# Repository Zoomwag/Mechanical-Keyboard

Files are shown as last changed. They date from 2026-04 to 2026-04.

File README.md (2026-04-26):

# Mechanical Keyboard

Render 1
Render 2
Render 3

These are some high-quality renders of the keyboard design.

---

## Overview

This is a custom mechanical keyboard that I designed from scratch. It is a **60% layout** and runs on a **Raspberry Pi Pico** using **QMK firmware**.

The goal of this project was to make the keyboard:
- Easy to build  
- Affordable and accessible  
- Fully DIY-friendly  

All components are **through-hole (THT)**, making soldering much easier—especially for beginners. The entire keyboard is assembled using just **four M3 screws**, keeping the construction simple and clean.

The case is fully **3D printable**, and the keycaps can either be 3D printed or purchased. I recommend buying keycaps for better durability and finish.

The keyboard uses **Cherry MX-style switches**, so you can choose whichever type suits your preference. I will likely be using **Cherry MX Red switches** for a smooth, linear feel.

---

## PCB

### PCB Layout
PCB Layout

### Schematic
Schematic

### 3D PCB Model
PCB 3D

### Fully Assembled PCB (3D View)
Assembled PCB 1
Assembled PCB 2
Assembled PCB 3

---

## Case

### Top Shell
Top Case

### Bottom Shell
Bottom Case

### Full Case (No Electronics)
Empty Case

### Electronics Installed
Assembled Case

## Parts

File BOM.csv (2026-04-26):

Name | Purpose | Quantity | Total Cost (USD) | Link | Distributor
UGREEN 3A USB Type C Cable For iPhone 17 16 Xiaomi Samsung Fast Charging Wire USB-C Charger Data Cord For iPad Poco USB C | cable | 1 | 3.00 | https://www.aliexpress.com/item/1005006471612403.html?mp=1 | ALiexpress
Pi pico | MCU | 1 | 3.00 | https://www.aliexpress.com/item/1005005617180169.html?curPageLogUid=uMiuSRCoFOSS | Aliexpress
Customization PCB Satellite Axis For Cherry Mechanical Keyboard OEM Plate mounted Black 6.25u 2u Stabilizers Modifier Keys | Stabalizers | 1 | 6.00 | https://www.aliexpress.com/item/1005001686299616.html?mp=1 | Aliexpress
125 Keys Minimalist White Japanese Keycaps For MX Switch Mechanical Keyboard Cherry Profile Dye Sublimation PBT Key Caps Custom | Keycaps | 1 | 12.00 | https://www.aliexpress.com/item/1005009695266144.html?curPageLogUid=n6jaXa30P5yE | AliExpress
100PCS do-35 1N4148 IN4148 High-speed switching diodes New In Stock | diodes | 2 | 2.00 | https://www.aliexpress.com/item/1005008962041349.html?curPageLogUid=TPSj3bbLctze | Aliexpress
10~120Pc Original Cherry MX Mechanical Keyboard Switches Red Blue Brown Black Silver Pink Linear Tactile Cherry Clear RGB Switch | switches | 1 | 24.00 | https://www.aliexpress.com/item/1005007907313874.html?curPageLogUid=7ZZJ3L4R22EP | ALiexpress
Pcb | Pcb | 1 | 20.30 | https://jlcpcb.com/ | jlcpcb

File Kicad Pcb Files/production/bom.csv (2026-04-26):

Designator | Footprint | Quantity | Value | LCSC Part #
A1 | RaspberryPi_Pico_Common_Unspecified | 1 | RaspberryPi_Pico
D1, D10, D11, D12, D13, D14, D15, D16, D17, D18, D19, D2, D20, D21, D22, D23, D24, D25, D26, D27, D28, D29, D3, D30, D31, D32, D33, D34, D35, D36, D37, D38, D39, D4, D40, D41, D42, D43, D44, D45, D46, D47, D48, D49, D5, D50, D51, D52, D53, D54, D55, D56, D57, D58, D59, D6, D60, D61, D7, D8, D9 | D_DO-35_SOD27_P7.62mm_Horizontal | 61 | D
SW1, SW10, SW11, SW12, SW13, SW16, SW17, SW18, SW19, SW2, SW20, SW21, SW22, SW23, SW24, SW25, SW26, SW27, SW3, SW30, SW31, SW32, SW33, SW34, SW35, SW36, SW37, SW38, SW39, SW4, SW40, SW43, SW44, SW45, SW46, SW47, SW48, SW49, SW5, SW50, SW51, SW52, SW6, SW7, SW8, SW9 | SW_Cherry_MX_1.00u_PCB | 46 | SW_Push
SW14 | SW_Cherry_MX_2.00u_PCB | 1 | bAKCPASCE
SW15 | SW_Cherry_MX_1.00u_PCB | 1 | 1.5
SW28 | SW_Cherry_MX_1.50u_PCB | 1 | BIG
SW29 | SW_Cherry_MX_1.75u_PCB | 1 | SW_Push
SW41 | SW_Cherry_MX_2.25u_PCB | 1 | ENTER
SW42 | SW_Cherry_MX_2.25u_PCB | 1 | MINI SHIFT
SW53 | SW_Cherry_MX_2.75u_PCB | 1 | BIGSHIFT
SW54 | SW_Cherry_MX_1.25u_PCB | 1 | FBDS
SW55 | SW_Cherry_MX_1.25u_PCB | 1 | DBFS
SW56 | SW_Cherry_MX_1.25u_PCB | 1 | SBFGD
SW57 | SW_Cherry_MX_6.25u_PCB | 1 | SPACE
SW58, SW59 | SW_Cherry_MX_1.25u_PCB | 2 | MID2
SW60 | SW_Cherry_MX_1.25u_PCB | 1 | MID1
SW61 | SW_Cherry_MX_1.25u_PCB | 1 | MID

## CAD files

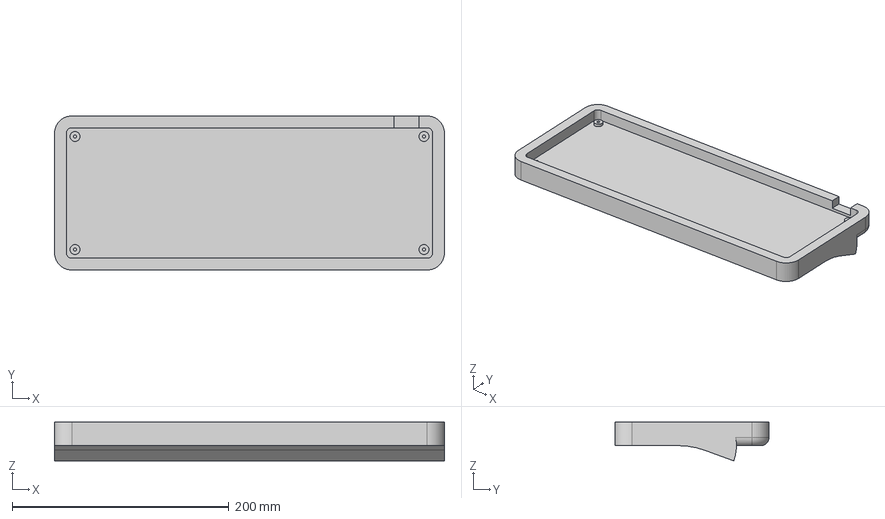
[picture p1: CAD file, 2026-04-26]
Cad Files/Bottom Case.step
360.0 x 142.2 x 35.7 mm

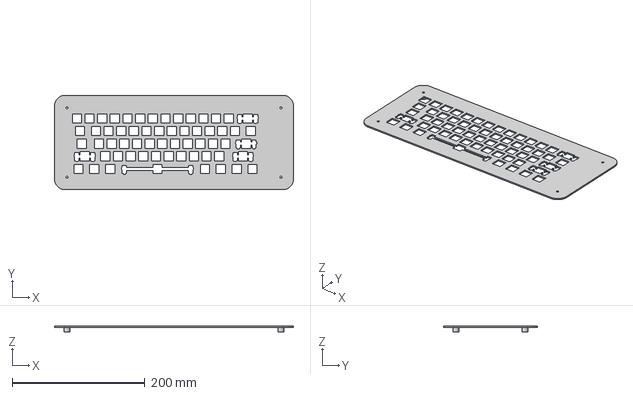
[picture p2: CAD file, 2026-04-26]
Cad Files/Top Case.step
360.0 x 142.2 x 9.19 mm

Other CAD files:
Cad Files/Bottom Case.f3d
Cad Files/Top Case.f3d

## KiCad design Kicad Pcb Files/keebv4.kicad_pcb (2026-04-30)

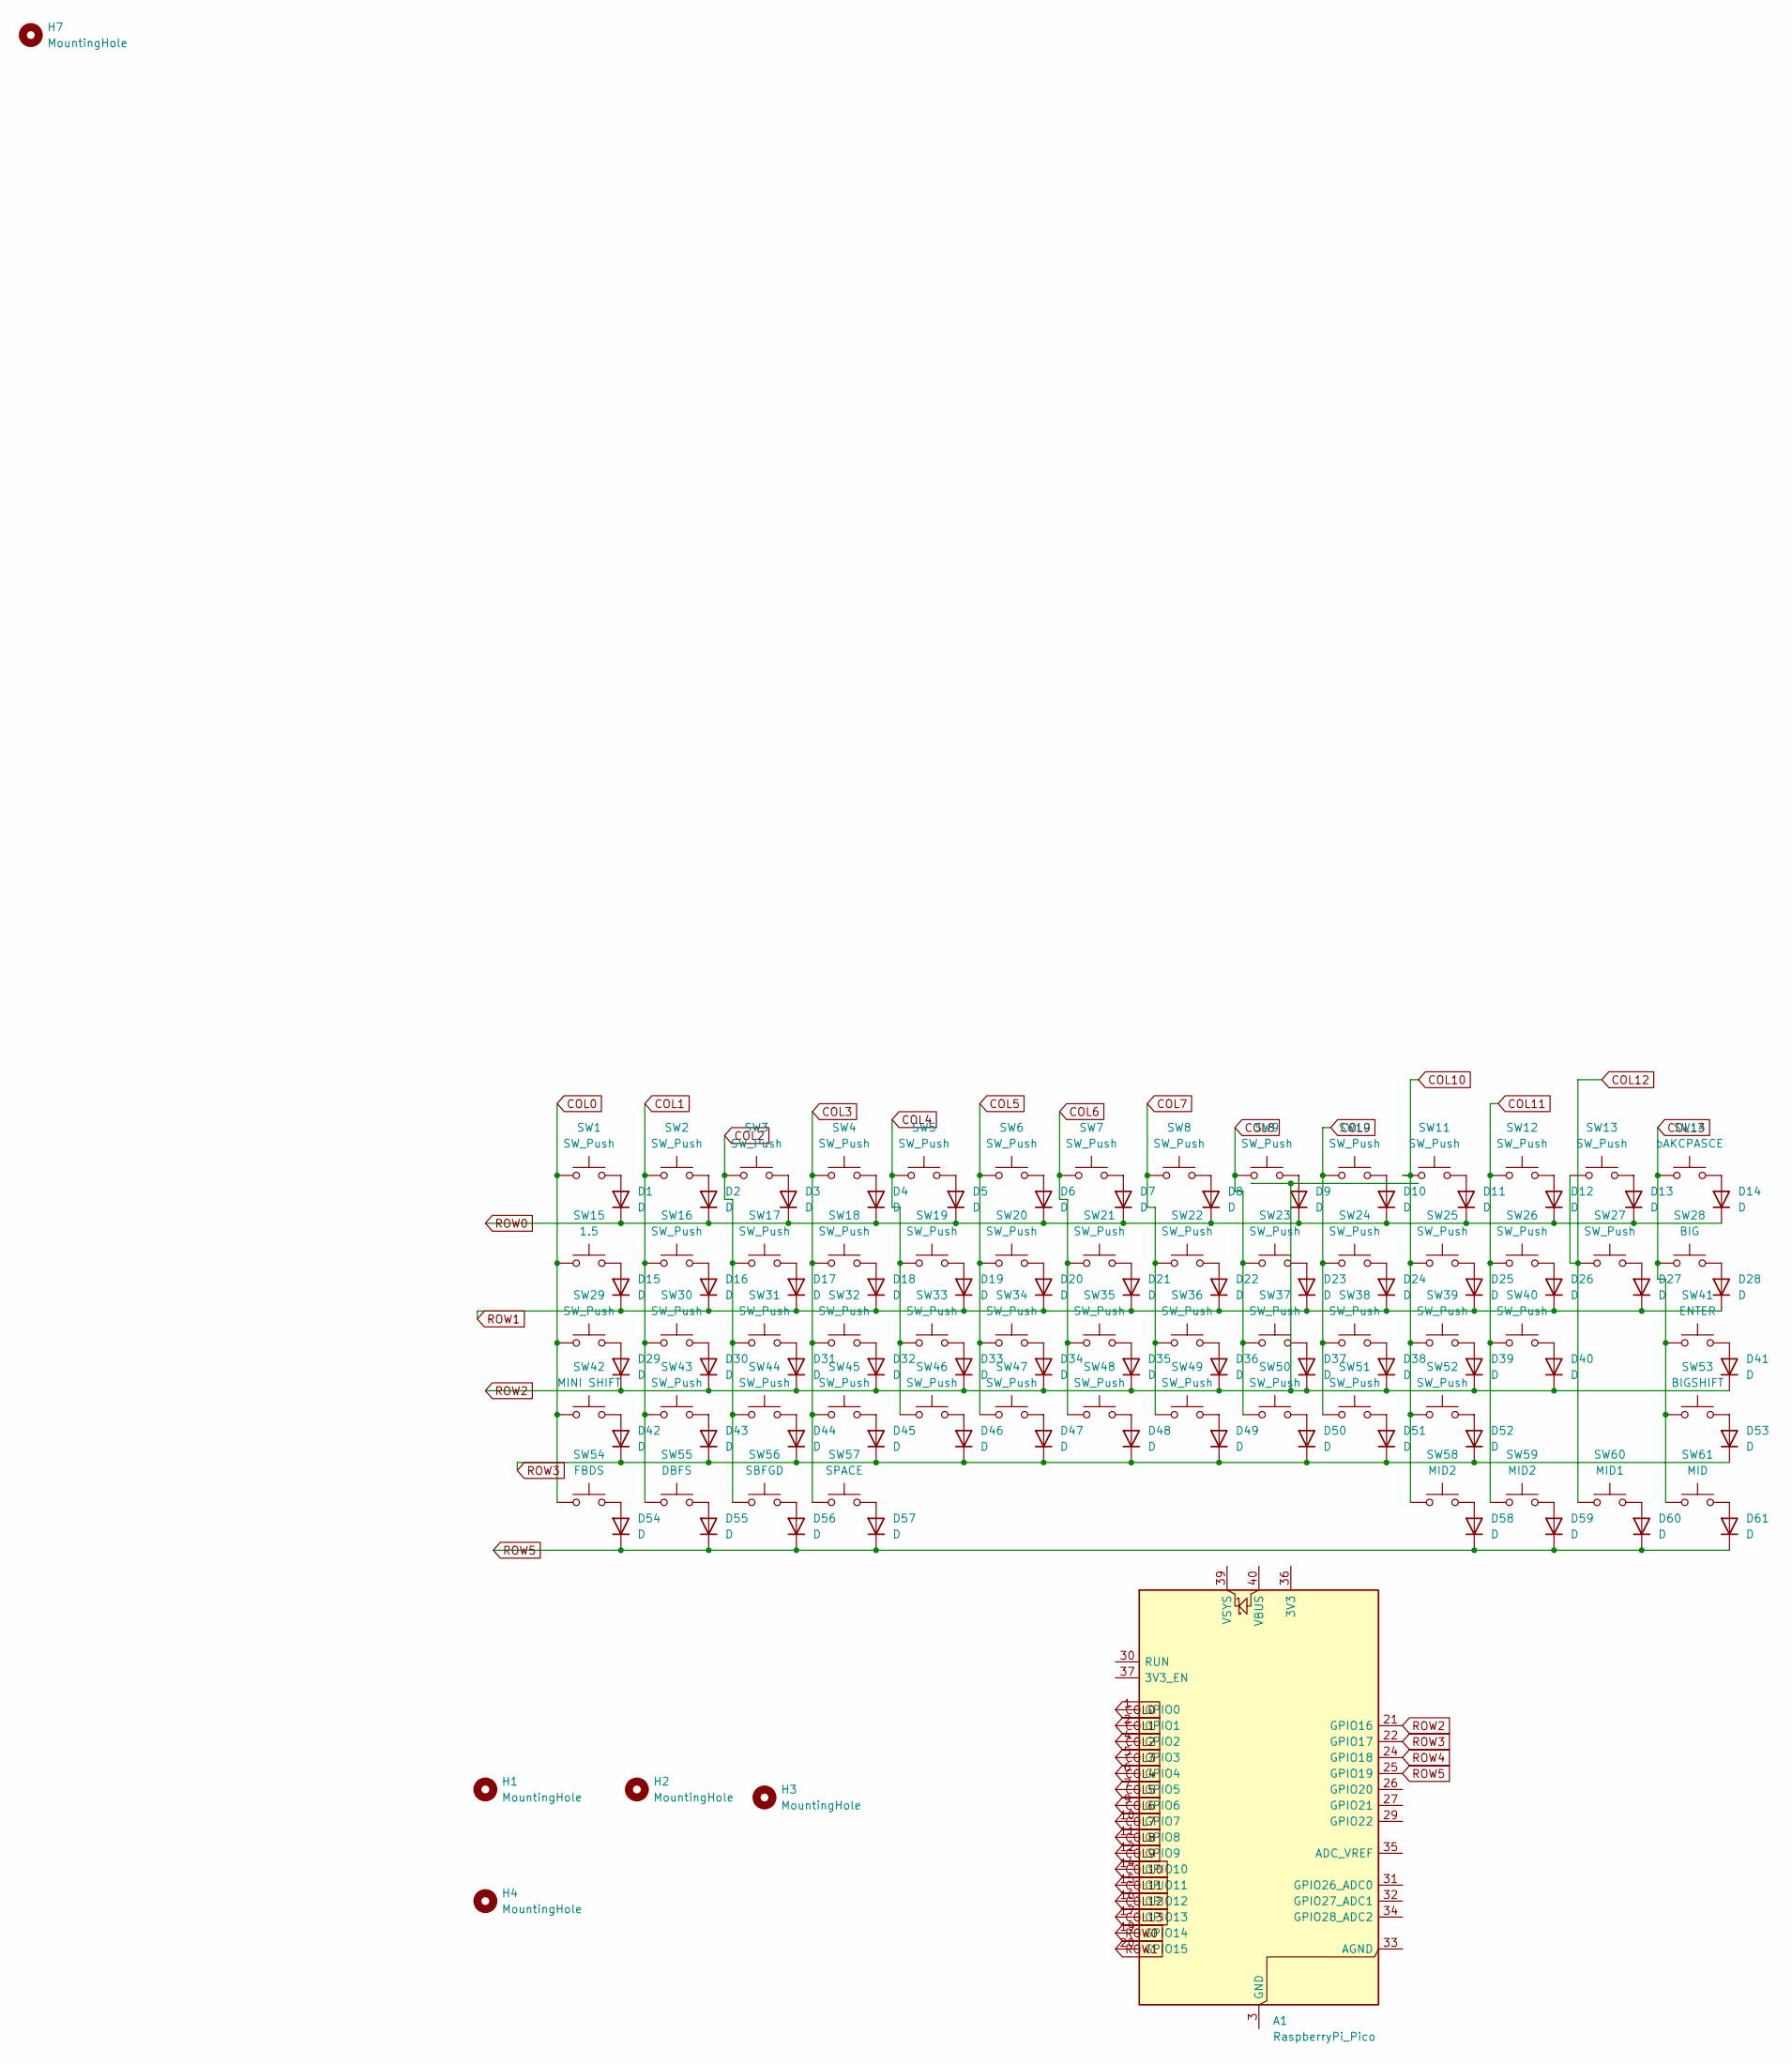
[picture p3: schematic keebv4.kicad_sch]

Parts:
A1: RaspberryPi_Pico; RaspberryPi_Pico_Common_Unspecified
D1, D2, D3, D4, D5, D6, D7, D8, D9, D10, D11, D12, D13, D14, D15, D16, D17, D18, D19, D20, D21, D22, D23, D24, D25, D26, D27, D28, D29, D30, D31, D32, D33, D34, D35, D36, D37, D38, D39, D40, D41, D42, D43, D44, D45, D46, D47, D48, D49, D50, D51, D52, D53, D54, D55, D56, D57, D58, D59, D60, D61: D; D_DO-35_SOD27_P7.62mm_Horizontal
H1, H2, H3, H4, H7: MountingHole; MountingHole_3.2mm_M3
SW1, SW2, SW3, SW4, SW5, SW6, SW7, SW8, SW9, SW10, SW11, SW12, SW13, SW16, SW17, SW18, SW19, SW20, SW21, SW22, SW23, SW24, SW25, SW26, SW27, SW30, SW31, SW32, SW33, SW34, SW35, SW36, SW37, SW38, SW39, SW40, SW43, SW44, SW45, SW46, SW47, SW48, SW49, SW50, SW51, SW52: SW_Push; SW_Cherry_MX_1.00u_PCB
SW14: bAKCPASCE; SW_Cherry_MX_2.00u_PCB
SW15: 1.5; SW_Cherry_MX_1.00u_PCB
SW28: BIG; SW_Cherry_MX_1.50u_PCB
SW29: SW_Push; SW_Cherry_MX_1.75u_PCB
SW41: ENTER; SW_Cherry_MX_2.25u_PCB
SW42: MINI SHIFT; SW_Cherry_MX_2.25u_PCB
SW53: BIGSHIFT; SW_Cherry_MX_2.75u_PCB
SW54: FBDS; SW_Cherry_MX_1.25u_PCB
SW55: DBFS; SW_Cherry_MX_1.25u_PCB
SW56: SBFGD; SW_Cherry_MX_1.25u_PCB
SW57: SPACE; SW_Cherry_MX_6.25u_PCB
SW58, SW59: MID2; SW_Cherry_MX_1.25u_PCB
SW60: MID1; SW_Cherry_MX_1.25u_PCB
SW61: MID; SW_Cherry_MX_1.25u_PCB

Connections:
COL0: A1.1 (GPIO0), SW1.1, SW15.1, SW29.1, SW42.1, SW54.1
COL1: A1.2 (GPIO1), SW2.1, SW16.1, SW30.1, SW43.1, SW55.1
COL2: A1.4 (GPIO2), SW3.1, SW17.1, SW31.1, SW44.1, SW56.1
COL3: A1.5 (GPIO3), SW4.1, SW18.1, SW32.1, SW45.1, SW57.1
COL4: A1.6 (GPIO4), SW5.1, SW19.1, SW33.1, SW46.1
COL5: A1.7 (GPIO5), SW6.1, SW20.1, SW34.1, SW47.1
COL6: A1.9 (GPIO6), SW7.1, SW21.1, SW35.1, SW48.1
COL7: A1.10 (GPIO7), SW8.1, SW22.1, SW36.1, SW49.1
COL8: A1.11 (GPIO8), SW9.1, SW23.1, SW37.1, SW50.1
COL9: A1.12 (GPIO9), SW10.1, SW24.1, SW38.1, SW51.1
COL10: A1.14 (GPIO10), SW11.1, SW25.1, SW39.1, SW52.1, SW58.1
COL11: A1.15 (GPIO11), SW12.1, SW26.1, SW40.1, SW59.1
COL12: A1.16 (GPIO12), SW13.1, SW27.1, SW60.1
COL13: A1.17 (GPIO13), SW14.1, SW28.1, SW41.1, SW53.1, SW61.1
unnamed: A1.3 (GND), A1.8 (GND), A1.13 (GND), A1.18 (GND), A1.23 (GND), A1.28 (GND), A1.38 (GND)
unnamed: D1.2 (A), SW1.2
unnamed: D2.2 (A), SW2.2
unnamed: D3.2 (A), SW3.2
unnamed: D4.2 (A), SW4.2
unnamed: D5.2 (A), SW5.2
unnamed: D6.2 (A), SW6.2
unnamed: D7.2 (A), SW7.2
unnamed: D8.2 (A), SW8.2
unnamed: D9.2 (A), SW9.2
unnamed: D10.2 (A), SW10.2
unnamed: D11.2 (A), SW11.2
unnamed: D12.2 (A), SW12.2
unnamed: D13.2 (A), SW13.2
unnamed: D14.2 (A), SW14.2
unnamed: D15.2 (A), SW15.2
unnamed: D16.2 (A), SW16.2
unnamed: D17.2 (A), SW17.2
unnamed: D18.2 (A), SW18.2
unnamed: D19.2 (A), SW19.2
unnamed: D20.2 (A), SW20.2
unnamed: D21.2 (A), SW21.2
unnamed: D22.2 (A), SW22.2
unnamed: D23.2 (A), SW23.2
unnamed: D24.2 (A), SW24.2
unnamed: D25.2 (A), SW25.2
unnamed: D26.2 (A), SW26.2
unnamed: D27.2 (A), SW27.2
unnamed: D28.2 (A), SW28.2
unnamed: D29.2 (A), SW29.2
unnamed: D30.2 (A), SW30.2
unnamed: D31.2 (A), SW31.2
unnamed: D32.2 (A), SW32.2
unnamed: D33.2 (A), SW33.2
unnamed: D34.2 (A), SW34.2
unnamed: D35.2 (A), SW35.2
unnamed: D36.2 (A), SW36.2
unnamed: D37.2 (A), SW37.2
unnamed: D38.2 (A), SW38.2
unnamed: D39.2 (A), SW39.2
unnamed: D40.2 (A), SW40.2
unnamed: D41.2 (A), SW41.2
unnamed: D42.2 (A), SW42.2
unnamed: D43.2 (A), SW43.2
unnamed: D44.2 (A), SW44.2
unnamed: D45.2 (A), SW45.2
unnamed: D46.2 (A), SW46.2
unnamed: D47.2 (A), SW47.2
unnamed: D48.2 (A), SW48.2
unnamed: D49.2 (A), SW49.2
unnamed: D50.2 (A), SW50.2
unnamed: D51.2 (A), SW51.2
unnamed: D52.2 (A), SW52.2
unnamed: D53.2 (A), SW53.2
unnamed: D54.2 (A), SW54.2
unnamed: D55.2 (A), SW55.2
unnamed: D56.2 (A), SW56.2
unnamed: D57.2 (A), SW57.2
unnamed: D58.2 (A), SW58.2
unnamed: D59.2 (A), SW59.2
unnamed: D60.2 (A), SW60.2
unnamed: D61.2 (A), SW61.2
ROW0: A1.19 (GPIO14), D1.1 (K), D2.1 (K), D3.1 (K), D4.1 (K), D5.1 (K), D6.1 (K), D7.1 (K), D8.1 (K), D9.1 (K), D10.1 (K), D11.1 (K), D12.1 (K), D13.1 (K), D14.1 (K)
ROW1: A1.20 (GPIO15), D15.1 (K), D16.1 (K), D17.1 (K), D18.1 (K), D19.1 (K), D20.1 (K), D21.1 (K), D22.1 (K), D23.1 (K), D24.1 (K), D25.1 (K), D26.1 (K), D27.1 (K), D28.1 (K)
ROW2: A1.21 (GPIO16), D29.1 (K), D30.1 (K), D31.1 (K), D32.1 (K), D33.1 (K), D34.1 (K), D35.1 (K), D36.1 (K), D37.1 (K), D38.1 (K), D39.1 (K), D40.1 (K), D41.1 (K)
ROW3: A1.22 (GPIO17), D42.1 (K), D43.1 (K), D44.1 (K), D45.1 (K), D46.1 (K), D47.1 (K), D48.1 (K), D49.1 (K), D50.1 (K), D51.1 (K), D52.1 (K), D53.1 (K)
ROW4: A1.24 (GPIO18)
ROW5: A1.25 (GPIO19), D54.1 (K), D55.1 (K), D56.1 (K), D57.1 (K), D58.1 (K), D59.1 (K), D60.1 (K), D61.1 (K)

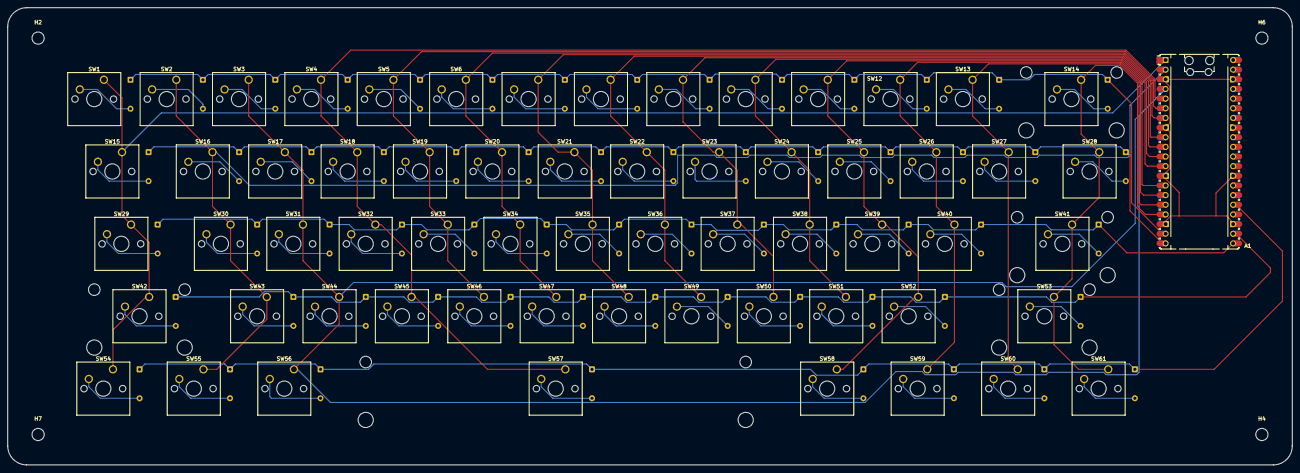
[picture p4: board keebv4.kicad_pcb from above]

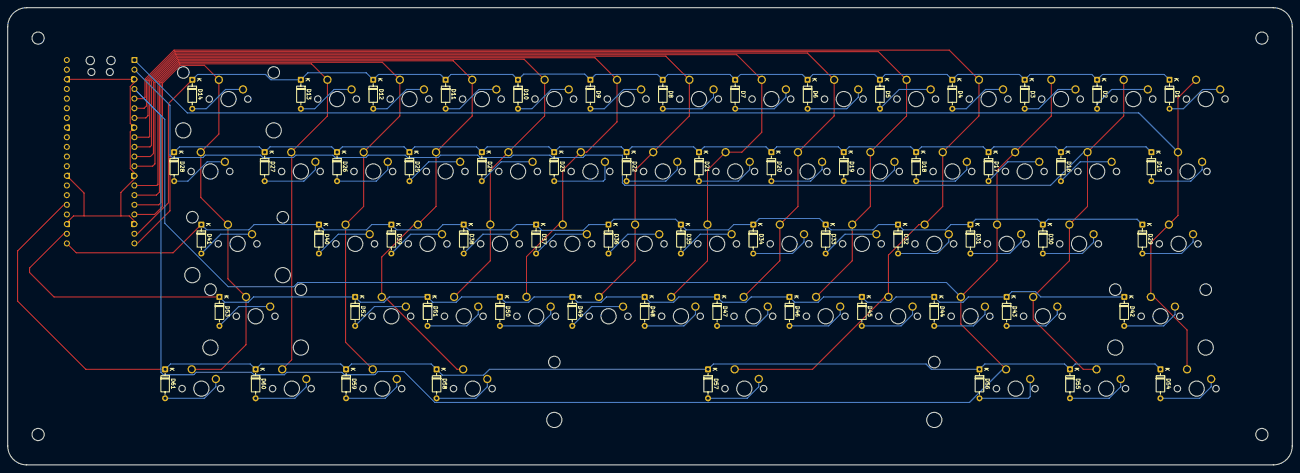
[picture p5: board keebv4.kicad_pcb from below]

Board: 2 copper layers, 338.1 x 120.3 mm, 127 parts (61 on the bottom side), 81 nets.

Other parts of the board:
H6: MountingHole; MountingHole_3.2mm_M3
